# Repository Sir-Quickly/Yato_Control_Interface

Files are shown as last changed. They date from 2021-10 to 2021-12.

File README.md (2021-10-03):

# Yato_Control_Interface
Interface Leiterplatte zur Fernsteuerung von  YATO (YG-04700)- und Hendi (3500 M)-Induktionsplatten 

Achtung: Im Betrieb und selbst im ausgeschalteten Zustand können auf der Leiterplatte potentiell gefährliche Spannungen anliegen, selbst nach dem Ziehen des Netzsteckers durch geladenen Kapzitäten.
Die Benutzung dieses Designs erfolgt auf eigenes Risiko und nur durch fachkundige Personen, die sich über die Gefahren und Risiken im Klaren sind.

Änderungen gegenüber V1.0
- Pulldown Widerstand für das On-Signal von der YATO Poti-Platine
- Pos. R4 korrigiert

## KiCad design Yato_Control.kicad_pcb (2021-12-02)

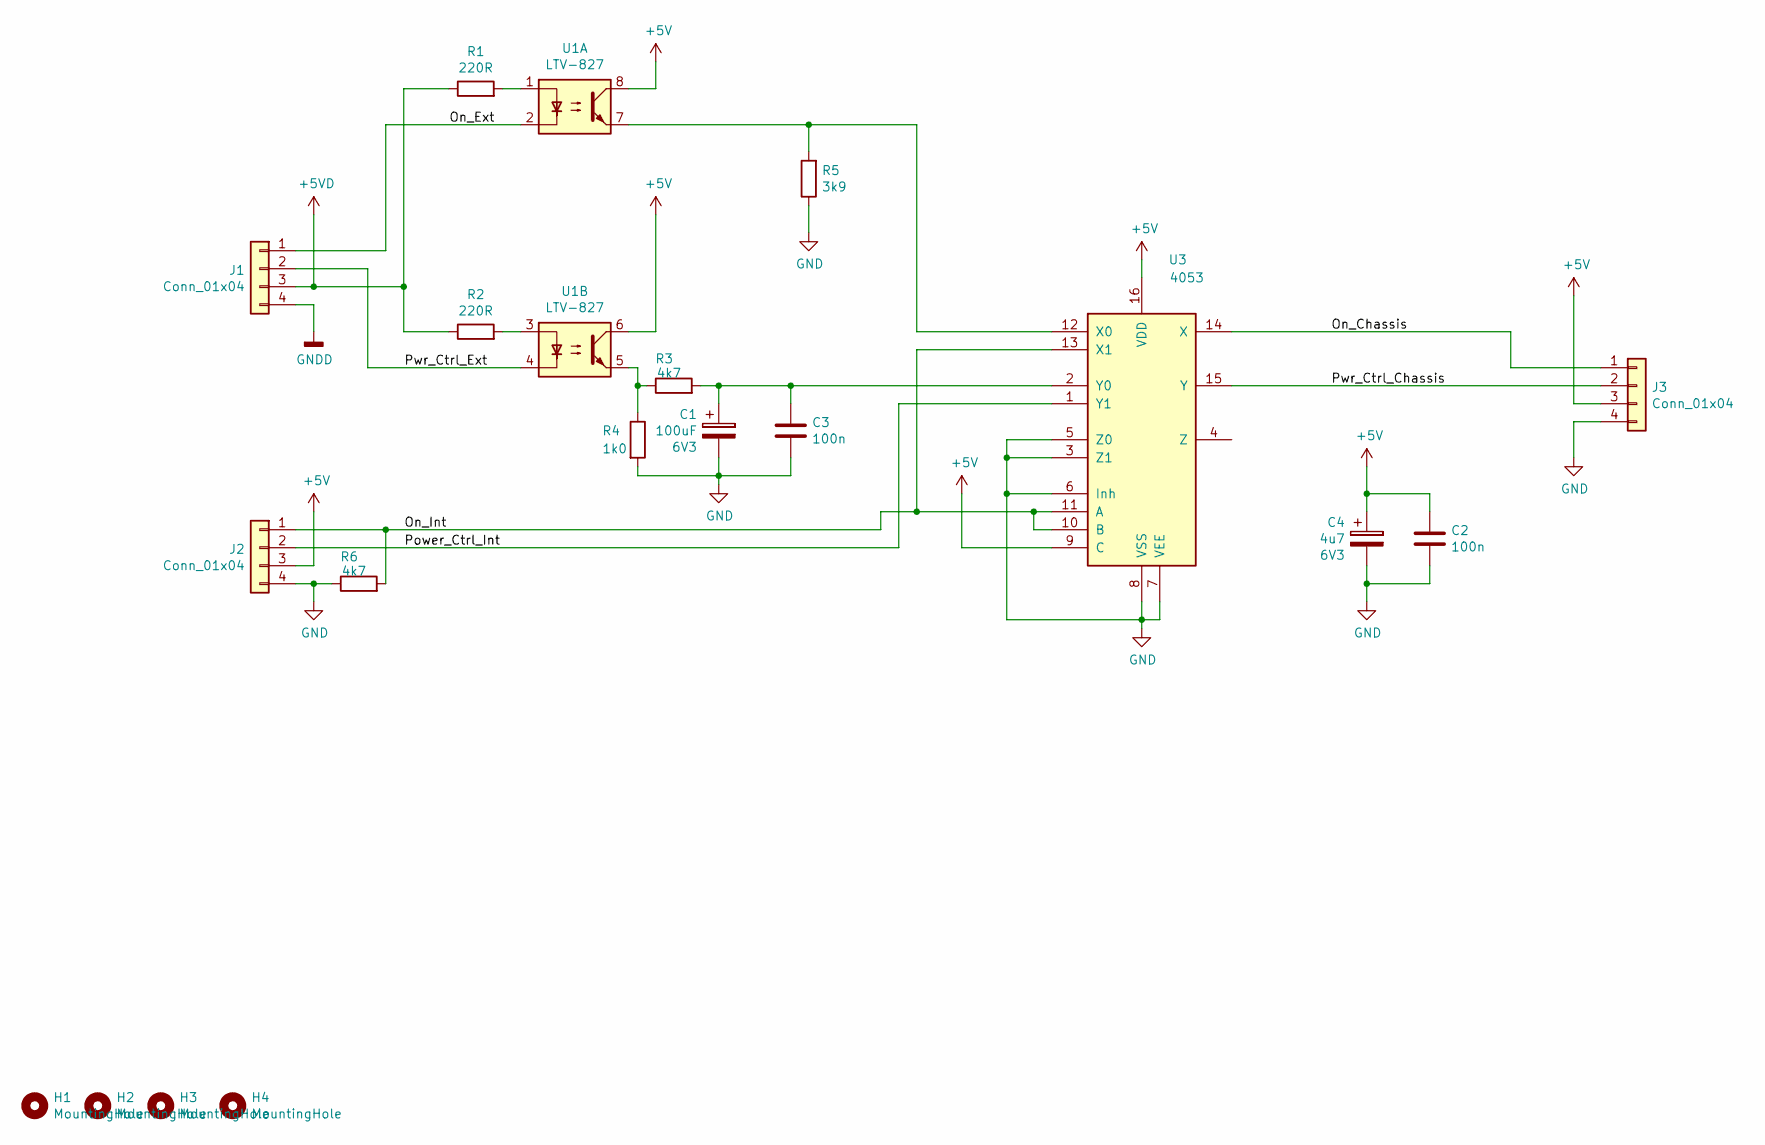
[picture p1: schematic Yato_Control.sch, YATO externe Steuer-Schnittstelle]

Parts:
C1: 100uF; CP_Radial_D10.0mm_P2.50mm_P5.00mm
C2, C3: 100n; C_Disc_D3.0mm_W1.6mm_P2.50mm
C4: 4u7; CP_Radial_D5.0mm_P2.50mm
H1, H2, H3, H4: MountingHole; MountingHole_4mm
J1, J2, J3: Conn_01x04; JST_XH_B04B-XH-A_1x04_P2.50mm_Vertical
R1, R2: 220R; R_Axial_DIN0207_L6.3mm_D2.5mm_P7.62mm_Horizontal
R3, R6: 4k7; R_Axial_DIN0207_L6.3mm_D2.5mm_P7.62mm_Horizontal
R4: 1k0; R_Axial_DIN0207_L6.3mm_D2.5mm_P7.62mm_Horizontal
R5: 3k9; R_Axial_DIN0207_L6.3mm_D2.5mm_P7.62mm_Horizontal
U1: LTV-827; DIP-8_W7.62mm
U3: 4053; DIP-16_W10.16mm

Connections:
+5V: C2.1, C4.1, J2.3, J3.3, U1.6, U1.8, U3.9 (C), U3.16 (VDD)
+5VD: J1.3, R1.1, R2.1
/On_Chassis: J3.1, U3.14 (X)
/On_Ext: J1.1, U1.2
/On_Int: J2.1, R6.2, U3.10 (B), U3.11 (A), U3.13 (X1)
/Power_Ctrl_Int: J2.2, U3.1 (Y1)
/Pwr_Ctrl_Chassis: J3.2, U3.15 (Y)
/Pwr_Ctrl_Ext: J1.2, U1.4
GND: C1.2, C2.2, C3.2, C4.2, J2.4, J3.4, R4.2, R5.1, R6.1, U3.3 (Z1), U3.5 (Z0), U3.6 (Inh), U3.7 (VEE), U3.8 (VSS)
GNDD: J1.4
unnamed: C1.1, C3.1, R3.2, U3.2 (Y0)
unnamed: R1.2, U1.1
unnamed: R2.2, U1.3
unnamed: R3.1, R4.1, U1.5
unnamed: R5.2, U1.7, U3.12 (X0)

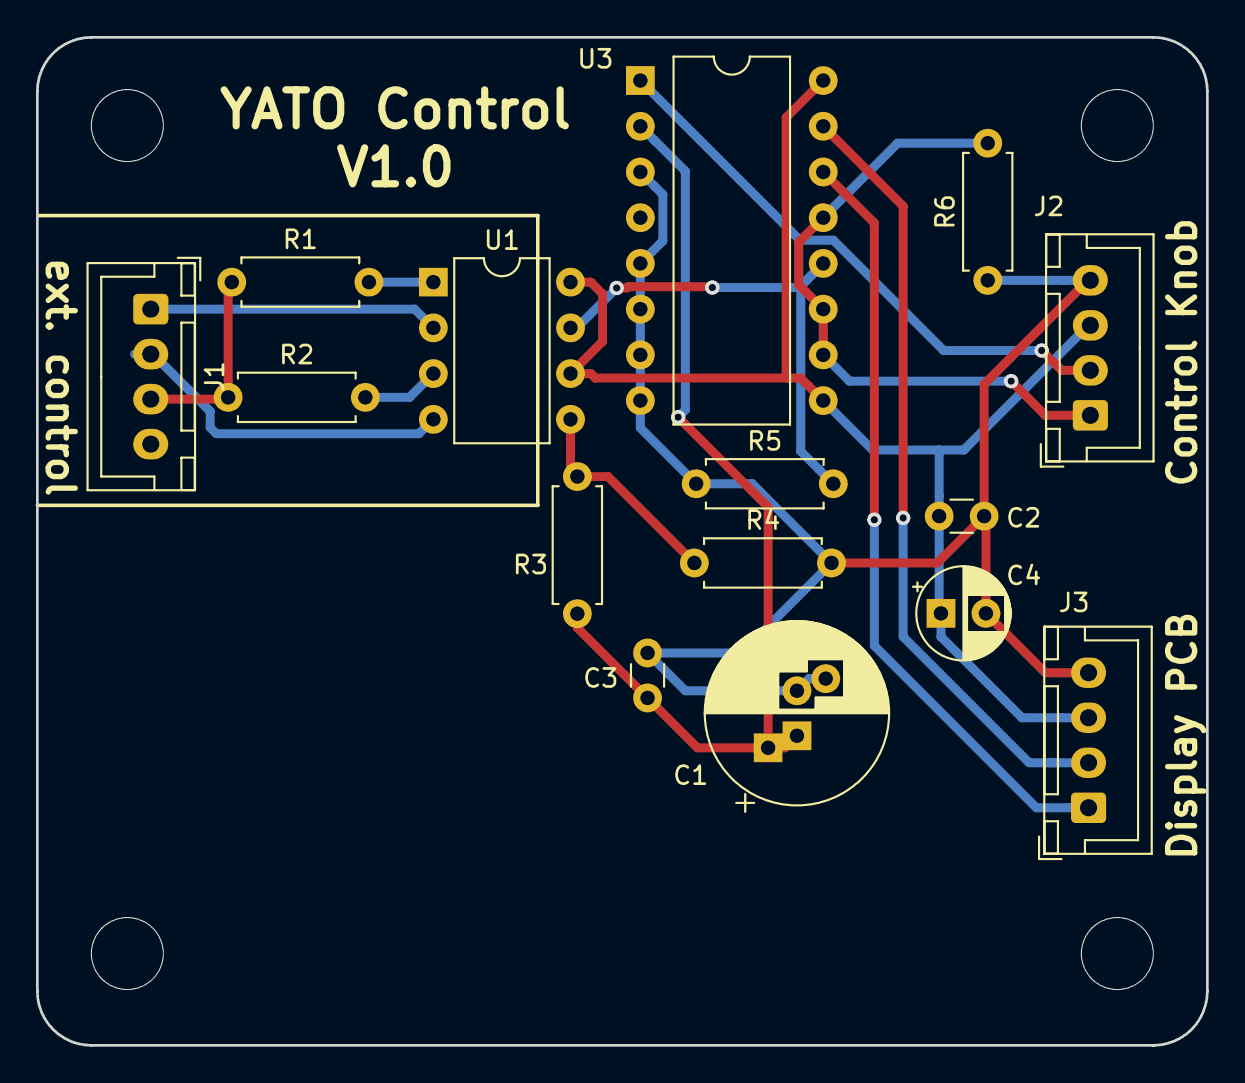
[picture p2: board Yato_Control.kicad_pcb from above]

Board: 2 copper layers, 65.0 x 56.0 mm, 19 parts (0 on the bottom side), 14 nets.

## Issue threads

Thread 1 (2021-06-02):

Thanks and one correction/addition

heyudude, 2021-06-02:
Hi,

Thanks for the PCB! Ordered it after adding the bottom mask to the layout (it was not selected) so the gerber files where generated correct. I do not know if it is something I did wrong or you can select by default in the KiCad project / board setup for others.

Any tips when I got the PCB? I read the German forum also so I know the support source ;)

heyudude, 2021-08-02:
Hi,
Small update. I used the pcb design and ordered it, added the bottom layer to the design.
I made it and mounted it in my Hendi 3500m. It works 👍🏼 great.
No issues, no diodes or anything else needed.
I use a control board of someone else's design, pwm signals.

Last Saturday I brewed a beer with it.
Thanks for the efforts publishing it.

Mvg

Dude

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

Sir-Quickly, 2021-08-04:
Hi Dude,

thanks for the feedaback and I glad to hear that you have fun with it.

Take care,
Sir Quickly

Am Mo., 2. Aug. 2021 um 16:53 Uhr schrieb Dude ***@***.***>:

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

Closed 2021-12-02.

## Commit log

2020-06-02 transferred project to Github inial commit
    [Yato_Control.kicad_pcb, Yato_Control.sch]
2020-06-05 initial layout done Signed-off-by: Sir Quickly <sir.quickly0@googlemail.com>
    [Yato_Control.kicad_pcb, Yato_Control.sch]
2020-07-25 - Pulldown Widerstand für das On-Signal von der YATO Poti-Platine - Pos. R4 korrigiert
    [Yato_Control.kicad_pcb, Yato_Control.sch]
